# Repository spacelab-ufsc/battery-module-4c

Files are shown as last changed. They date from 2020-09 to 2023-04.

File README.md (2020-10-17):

<h1 align="center">
	BATTERY MODULE 4 CELLS
	<br>
</h1>

<h4 align="center">Electrical power system battery module 4 cells hardware project (sources, outputs, and documentation).</h4>

<p align="center">
    <a href="">
		
	</a>
    <a href="https://github.com/spacelab-ufsc/battery-module-4c/releases">
		
	</a>
	<a href="">
		
	</a>
	<a href="">
		
	</a>
	<a href="https://github.com/spacelab-ufsc/eps2">
		
	</a>
</p>

<p align="center">
  	<a href="#overview">Overview</a> •
  	<a href="#architecture">Architecture</a> •
  	<a href="#interface">Interface</a> •
  	<a href="#version">Version</a> •
  	<a href="#license">License</a> •
  	<a href="#notes">Notes</a>
</p>

<p align="center">
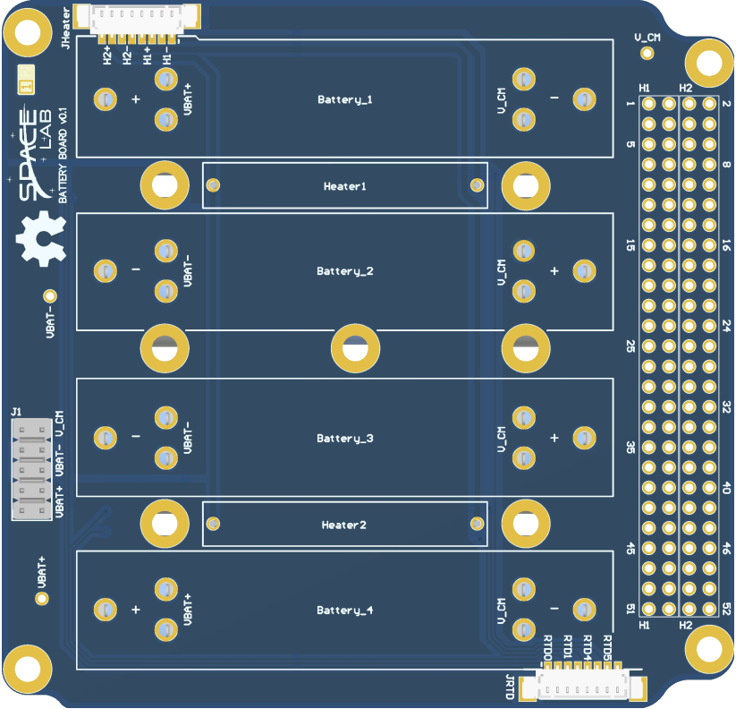
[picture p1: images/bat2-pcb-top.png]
	
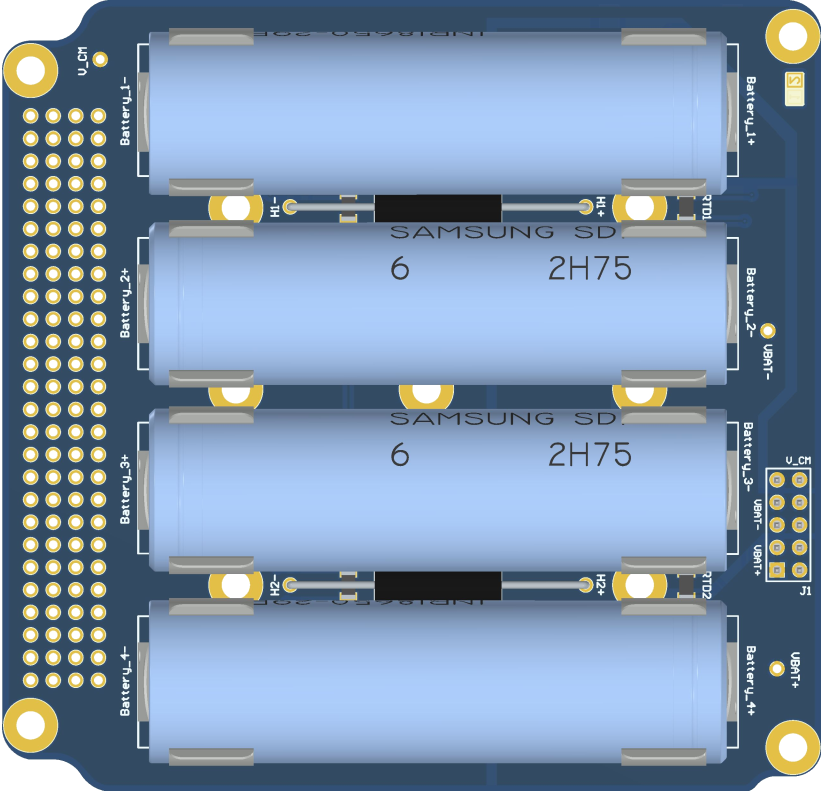
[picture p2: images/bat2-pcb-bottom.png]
	
</p>

## Overview

## Architecture

## Interface

## Version

The current version of the project is v0.1, the status is ```development```.

## License

This project is licensed under CERN Open Hardware License, version 2.

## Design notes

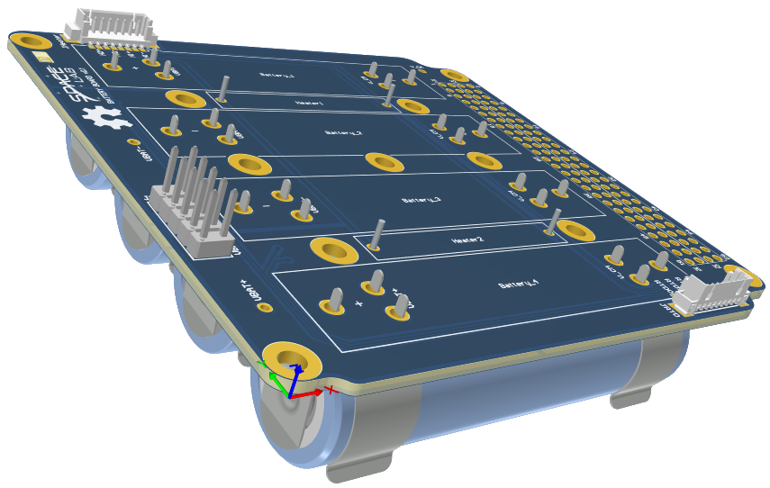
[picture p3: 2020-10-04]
images/bat2-pcb-3d.png

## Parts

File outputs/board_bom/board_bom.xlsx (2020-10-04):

 |  |  | Bill of Materials
 |  |  | Source Data From: | Field=bat2_project
 |  |  | Project: | Field=bat2_project
 |  |  | Variant: | Field=none
 |  |  | Project Code: | Field=BAT2
 |  |  | Report Date: | Field=ReportDate | Field=ReportTime
 |  |  | Print Date: | 2020-10-03 | 20:38:37
# | Column=Designator | Column=Quantity | Column=Manufacturer | Column=Manufacturer Part Number | Column=Partnumber | Column=Description | Column=Package | Column=Footprint | Column=Mount | Column=Fitted
1 | RTD1, RTD2, RTD3, RTD4 | 4 | Heraeus Nexensos |  | 32207595 | Board Mount Temperature Sensors SMD1206(V) Pt 1000 Class B -50 to +130C | 1206 (3216 Metric) | THRMC3216X70N | SMD | Fitted
2 | Battery_1-, Battery_1+, Battery_2-, Battery_2+, Battery_3-, Battery_3+, Battery_4-, Battery_4+ | 8 | Keystone Electronics |  | 54 | Cylindrical Battery Contacts, Clips, Holders & Springs 16-19mm PC BATTERY CLIP | Cylindrical Contact Clip | 54 | Through Hole | Fitted
3 | JHeater, JRTD | 2 | Molex |  | 532610871 | Connector Header Surface Mount, Right Angle 8 position 0.049" (1.25mm) | PicoBlade 53261 | 532610871 | SMD | Fitted
4 | J1 | 1 | SAMTEC |  | 67996-110HLF | Connector | Male Pin Header | HDRV10W64P254_2X5_1270X502X521P | Through Hole | Fitted
5 | PC104A, PC104B | 2 | SAMTEC |  | ESQ-126-39-G-D | PC / 104 Connectors .100" PC/104 Elevated Socket Strip | Forked Elevated Socket | ESQ-126-Y-X-D | Through Hole | Fitted
6 | Heater1, Heater2 | 2 | Vishay |  | RS02B24R00FE12 | Wirewound Resistors - Through Hole 3watts 24ohms 1% | Wirewound Resistors - Through Hole | RESAD3322W86L1422D475 | Through Hole | Fitted

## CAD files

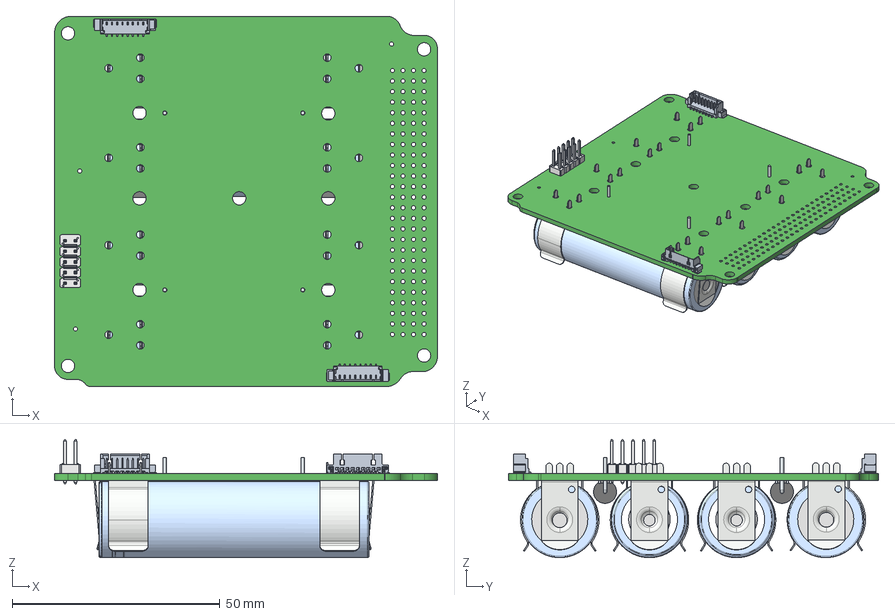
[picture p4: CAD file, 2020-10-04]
outputs/board_3dmodels/step_3dmodel.step
92.1 x 89.1 x 28.5 mm
Boardboard_layout
term1 x 4
term2 x 4
67996-x10_asm_RGB13421772
SimpleBody x 2
Samsung_INR18650-29R x 4
KEYELCO_54 x 8

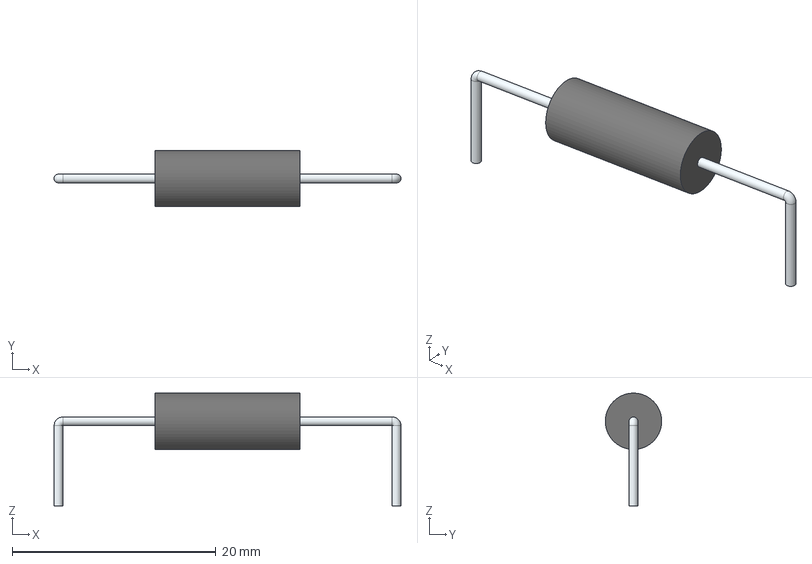
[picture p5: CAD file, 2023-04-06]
sources/ALTIUM_EMBEDDED_MODELS/RS02B24R00FE12.stp
34.1 x 5.53 x 11.1 mm
SimpleBody

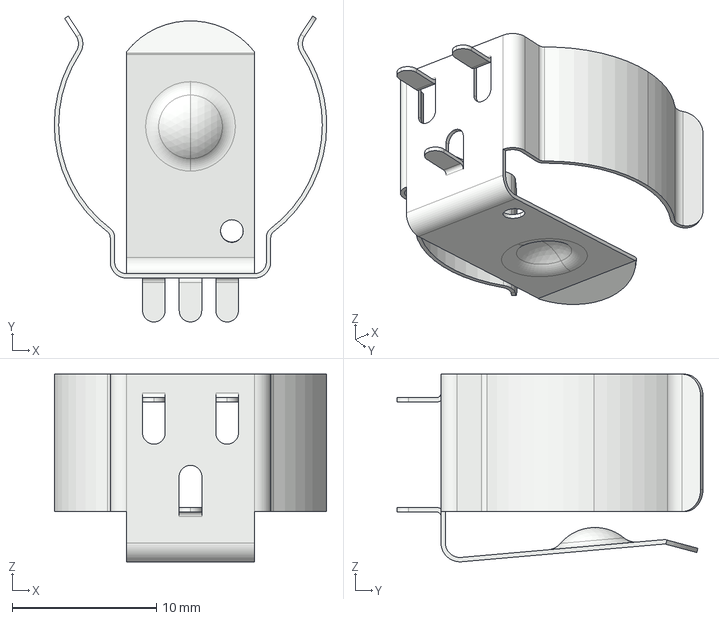
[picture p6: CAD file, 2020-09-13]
sources/ALTIUM_EMBEDDED_MODELS/KEYELCO_54.STEP
18.9 x 21.2 x 13.0 mm

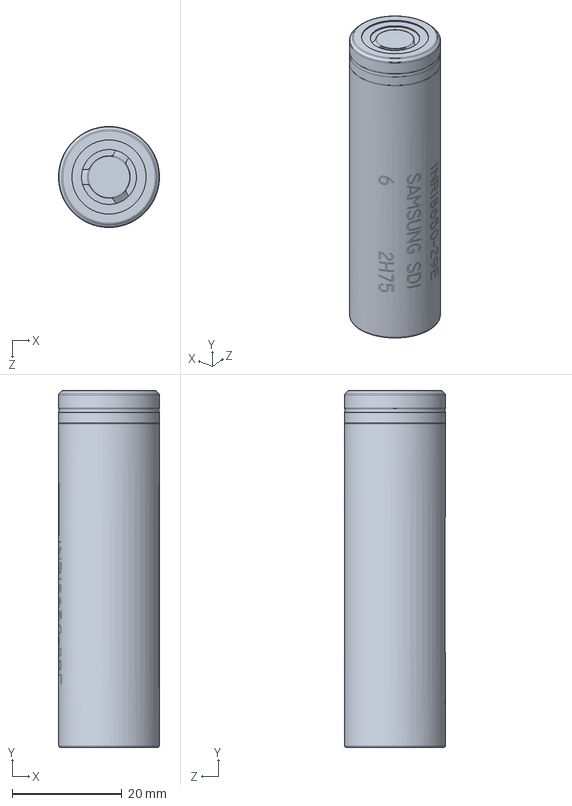
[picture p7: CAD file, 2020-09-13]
sources/ALTIUM_EMBEDDED_MODELS/Samsung INR18650-29R.SLDPRT
18.4 x 64.9 x 18.4 mm

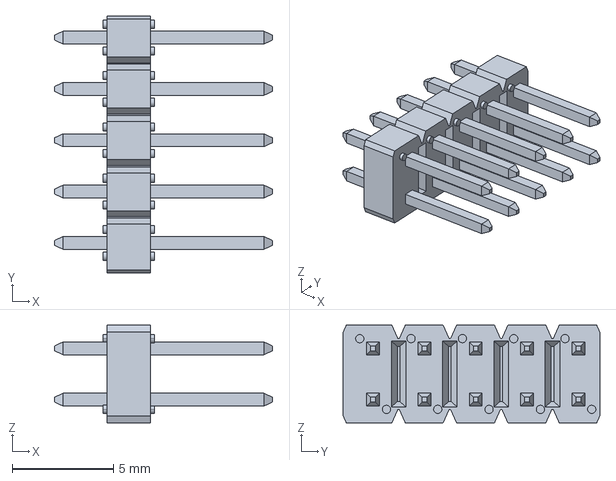
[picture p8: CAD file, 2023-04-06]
sources/ALTIUM_EMBEDDED_MODELS/67996-x10_asm.stp
10.8 x 12.7 x 4.83 mm

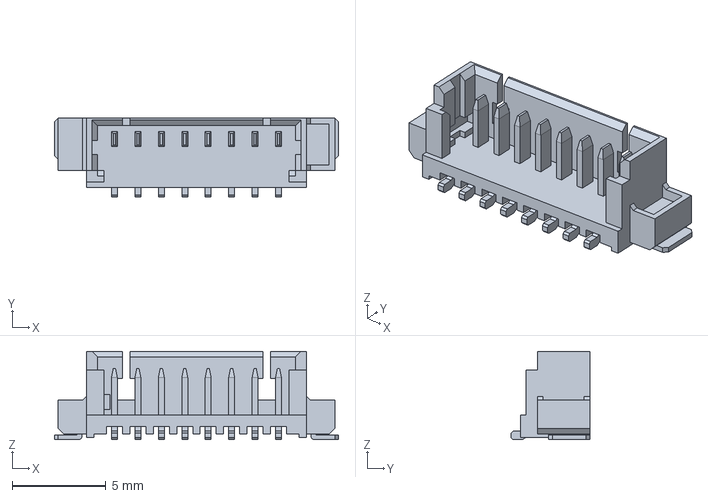
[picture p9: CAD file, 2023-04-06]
sources/ALTIUM_EMBEDDED_MODELS/53398-0871.stp
15.2 x 4.20 x 4.70 mm

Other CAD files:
outputs/board_3dmodels/parasolid_3dmodel.x_t

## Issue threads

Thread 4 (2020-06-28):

Hardware: Review mechanical attachment method

andrempmattos, 2020-06-28:
**Overview:**
It is necessary to review the mechanical attachment for a plastic/polymer cover/wrapper. Since there are 4 batteries and the terminals are closer, shortcuts or detachment could be a problem during the vibration tests patterns. Also, the wrapper presents assembly challenges during the integration, then a simpler method could ease these procedures and improve the overall feasibility.

**Some ideas/recomendations/suggestions to be analysed:**

It could improve the wrapper attachment in the PCB since there are no loose pieces/bolts/washer:
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

Maybe the same method used in other electronic devices with the plastic borders attached even without bolts:

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

YanAzer, 2021-02-10:
Some new images for inspiration:
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
https://www.google.com/imgres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
https://www.google.com/imgres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

YanAzer, 2021-04-28:
@spacelab-ufsc/mechanical some new ideas for the new mechanical case:

1) Add new mouting holes between the batteries, this will require them to be a bit por spaced.

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

2) Add a "tab" on the sides of the pcb to be enable placing the required mouting holes.

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

kiqsmg, 2021-04-28:
Both options can work, but I still prefer the first one because it only requires to create more space between batteries and also helps to have a better fixation points (the closer the fixations are, the less vibration problems and bending possibility).

Closed 2021-06-15.

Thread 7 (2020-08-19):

Hardware: Change PC104 conector partnumber

andrempmattos, 2020-08-19:
Change the PC104 partnumber to **SSW-126-01-G-D**.

andrempmattos, 2020-09-29:
The PC104 should not be soldered in this board. Then, the partnumber is not important anymore.

Closed 2020-09-29.

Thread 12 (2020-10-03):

Change the 8 pin PicoBlade vertical connector to the right angle version

YanAzer, 2020-10-03:
Current one is [0533980871](https://www.digikey.com/en/products/detail/molex/0533980871/699072), for better compatibility this component should be changed to the right angle version [0532610871](https://www.digikey.com/en/products/detail/molex/0532610871/699100).

andrempmattos, 2020-10-04:
The current version uses a 0532610871 (the right one) in the BOM file, but the 0533980871 in the board footprint/3D render. Then, it is important to update the footprint/3D render as suggested.

YanAzer, 2021-01-22:
@andrempmattos fixed solved issue via commits 626e60e940f685972dce35918c38ef1ae062296c and e58543fbc46f1a04be224ae19969c023d9c77b60, new outputs were generated via 2595ccffb678d09d9985b111dd0b83d6000be54a.

Closed 2021-01-22.

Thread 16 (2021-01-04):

Evaluate the battery choosed

andrempmattos, 2021-01-04:
https://ieeexplore.ieee.org/document/8281113

andrempmattos, 2021-01-04:
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

YanAzer, 2021-07-03:
I think we can close this issue, what you do you think @andrempmattos @mgm8?

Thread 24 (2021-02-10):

See a battery supplier alternative

YanAzer, 2021-02-10:
It would be better to choose another battery from the issue https://github.com/spacelab-ufsc/battery-module-4c/issues/16 and its provider.

YanAzer, 2021-05-27:
This issue is already covered in another repository.

Closed 2021-05-27.

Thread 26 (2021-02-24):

Hardware: Make the "bms" schematic sheet

YanAzer, 2021-02-24:
This schematic will have the battery controller IC https://github.com/spacelab-ufsc/battery-module-4c/issues/17 and auxiliary circuitry.

YanAzer, 2021-04-04:
@zdaniz22 next time remember to add the commits with its hashtag of its respective issue if you can, if not you can manually add the commit in the comments, just like what i am doing now 16429ef43a68dd4f7830682af033f33ba348b9a7

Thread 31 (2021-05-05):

Hardware: Evaluate 0 ohm jumper to isolate energized battery pack during integration

YanAzer, 2021-05-05:
For the next version of the BAT4C the batteries will be directly soldered to the PCB, it might be a good option to have a zero ohm jumper easily acessed on the side of the PCB to be soldered after the integration is done.

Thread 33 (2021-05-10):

Move the battery cells to the top side of the board

mgm8, 2021-05-10:

YanAzer, 2021-06-11:
@mgm8 it was discussed that the mounting holes previously on v0.1 for the mechanical batteries case would not be very pratical and might cause structure integrity problems because of the width of the material been drilled. #34

Closed 2021-06-11.

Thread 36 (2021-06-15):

Hardware: Evaluate the 3 wire configuration for RTDs

YanAzer, 2021-06-15:
Current design makes the 2 wire RTDs connections very inaccurate. Instead of 4 it can be used 2 RTDs with more precision in this 3 wire configuration directly below the heaters.
Reference: https://www.ti.com/lit/an/sbaa275/sbaa275.pdf?ts=1623687678741&ref_url=https%253A%252F%252Fwww.google.com%252F

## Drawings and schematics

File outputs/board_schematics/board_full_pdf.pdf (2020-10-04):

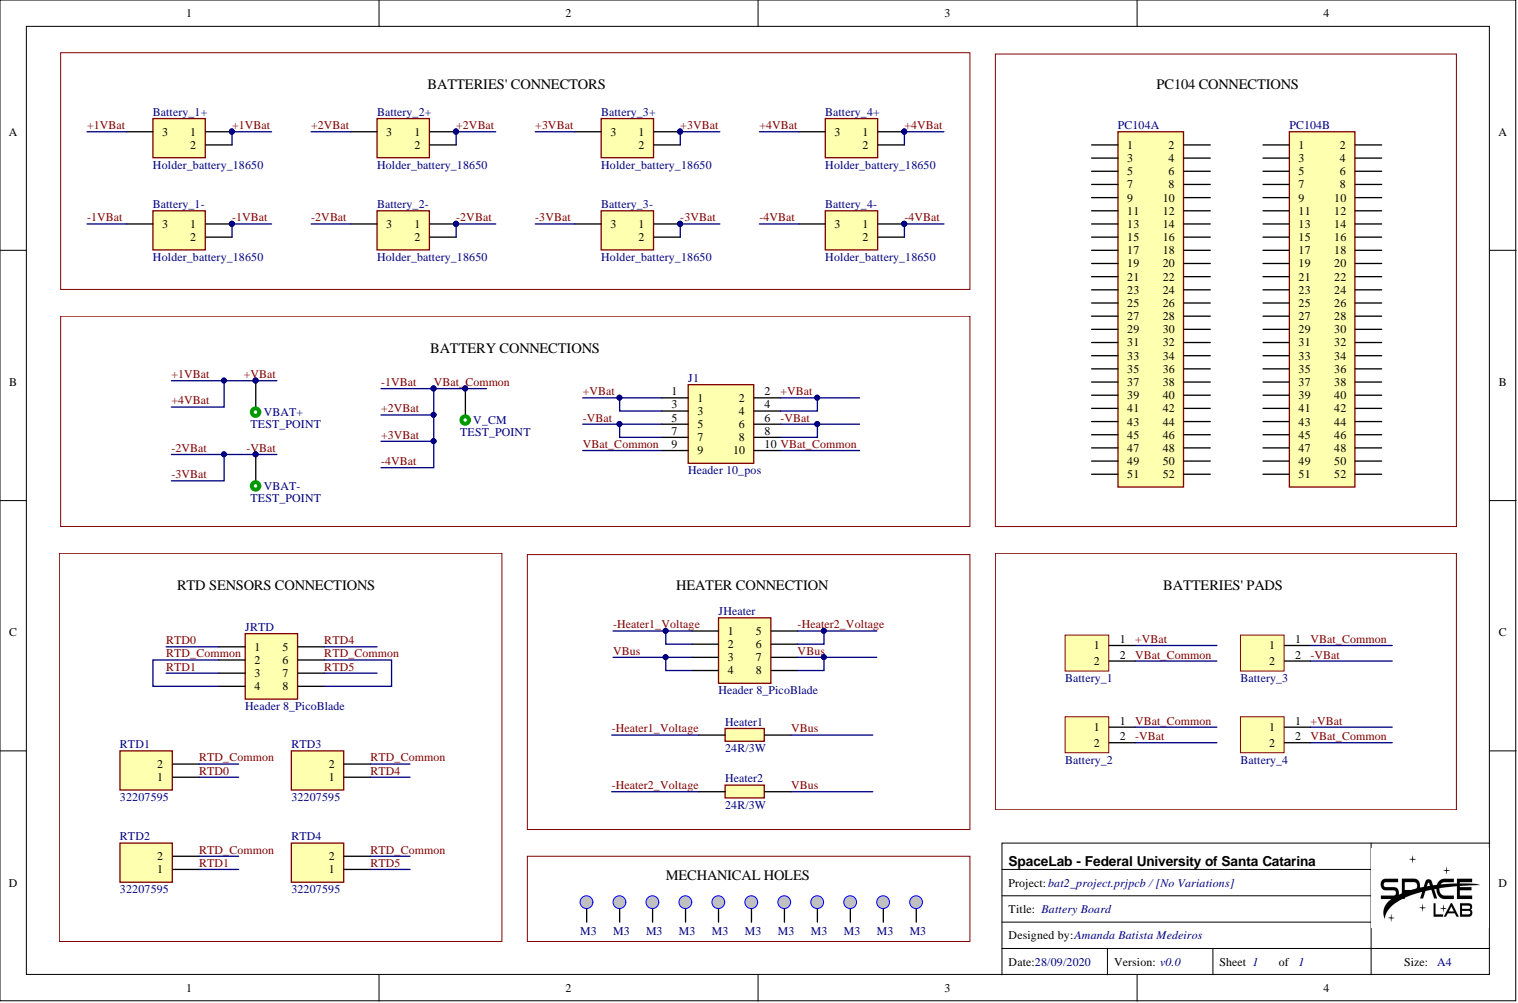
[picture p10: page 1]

SpaceLab - Federal University of Santa Catarina

Designed by:Amanda Batista Medeiros

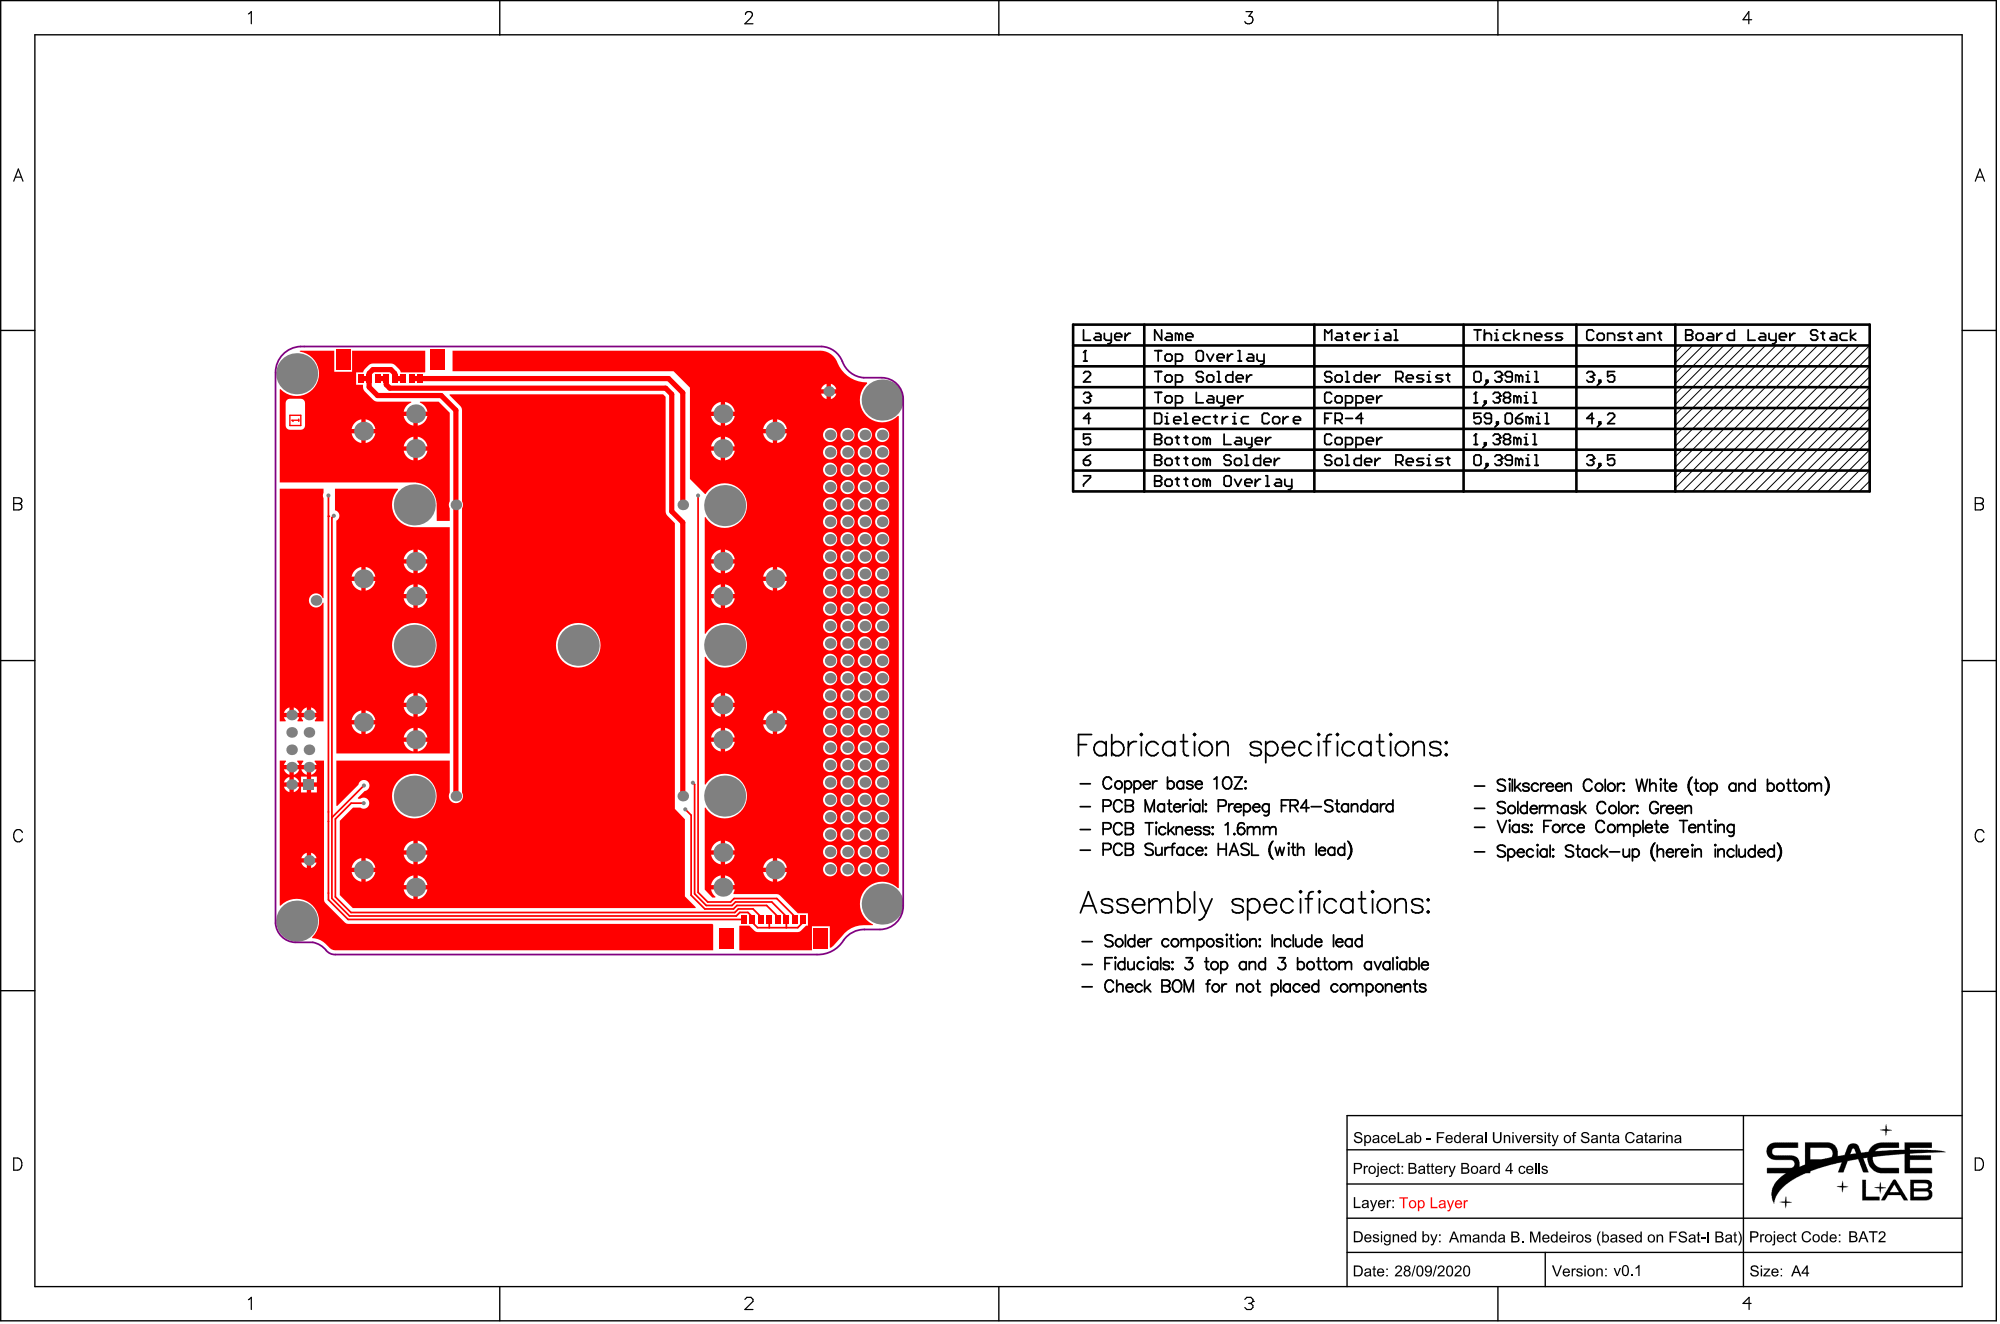
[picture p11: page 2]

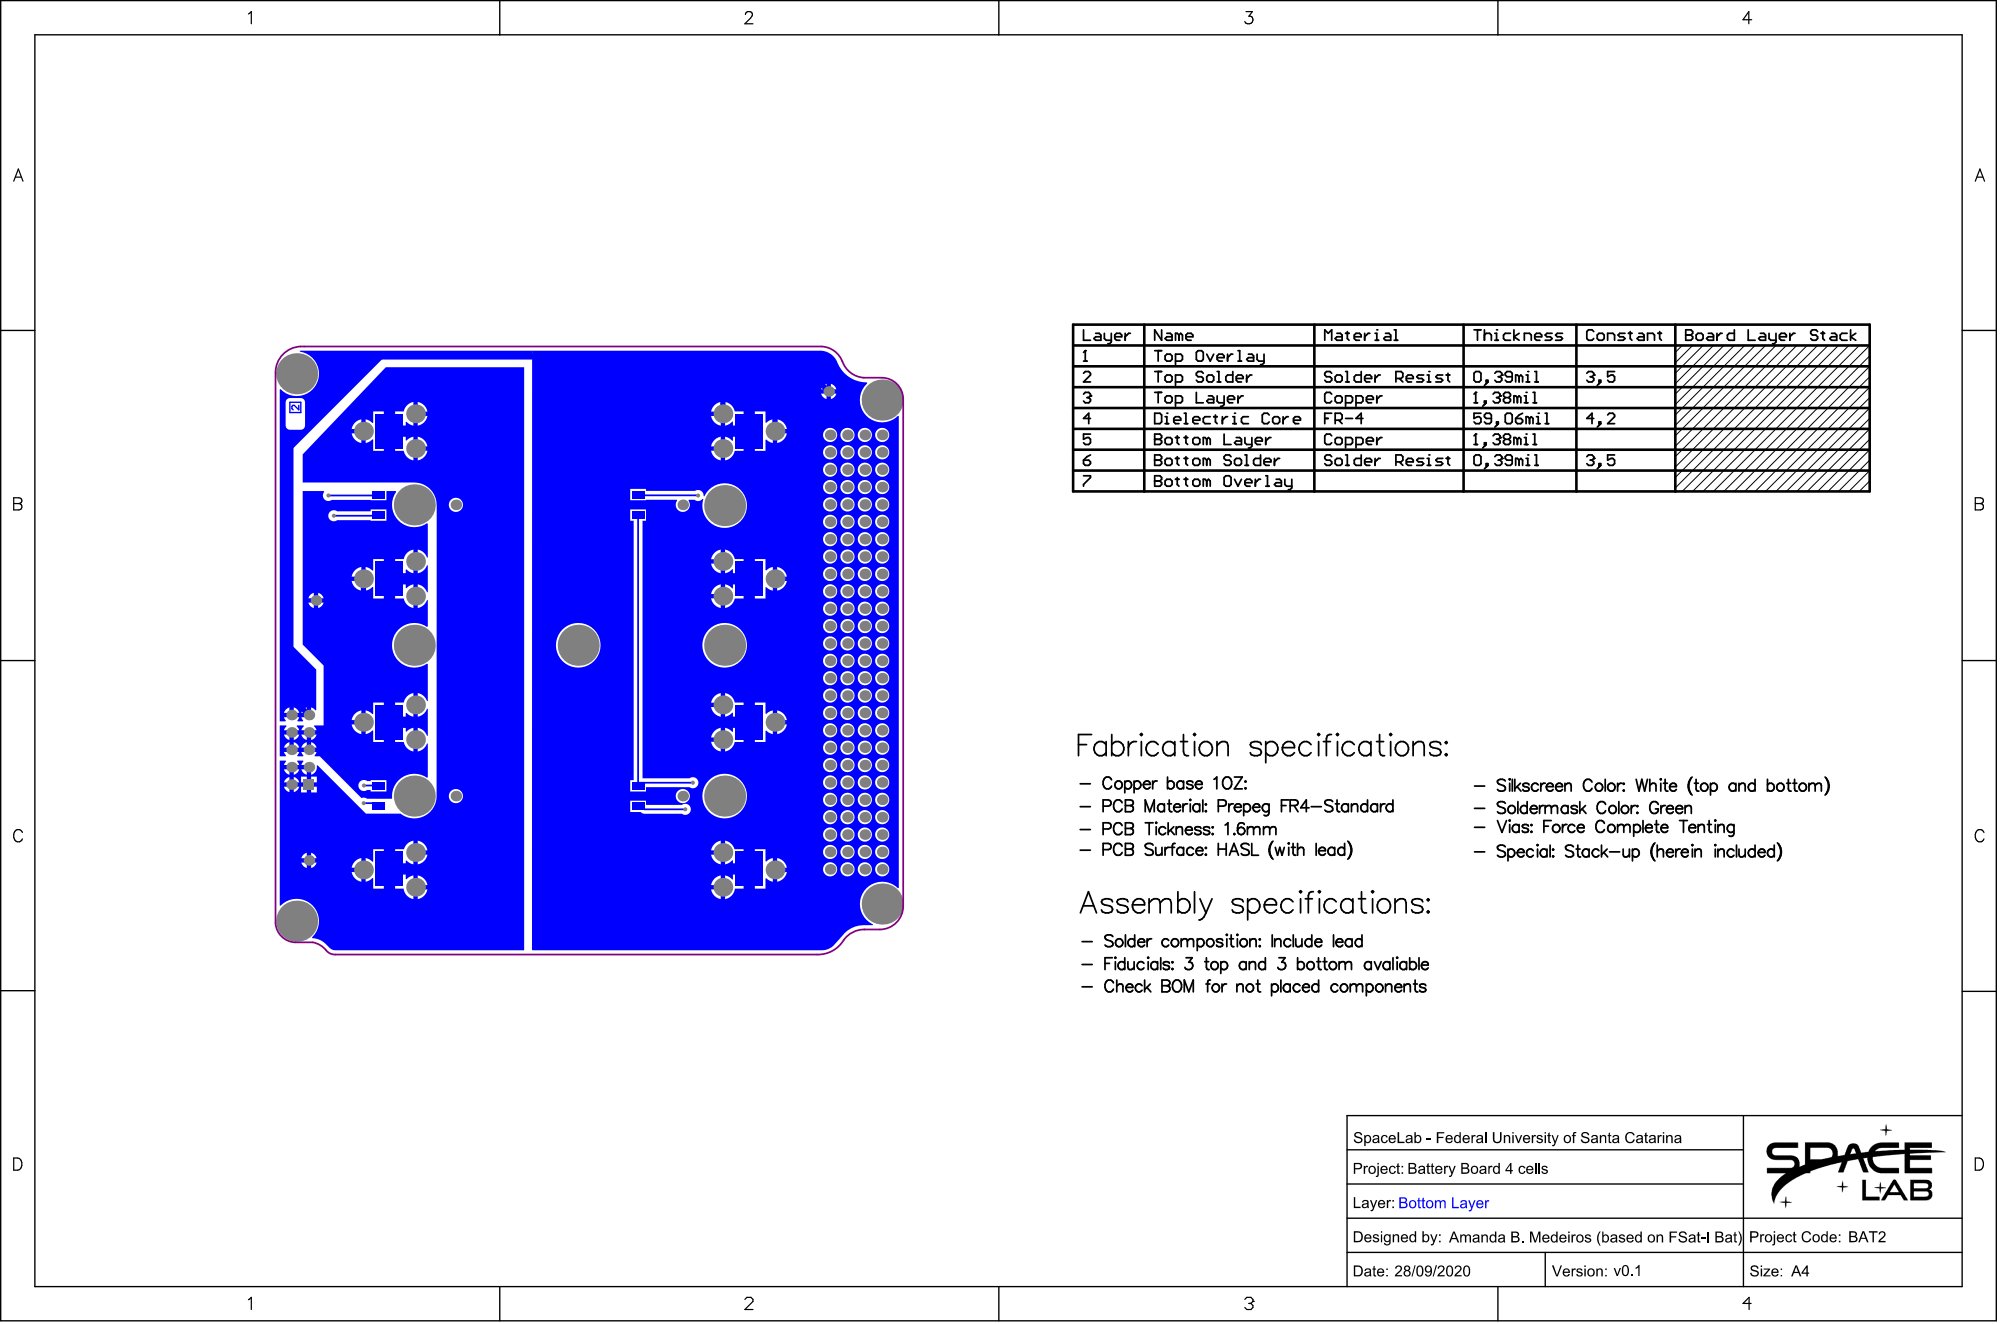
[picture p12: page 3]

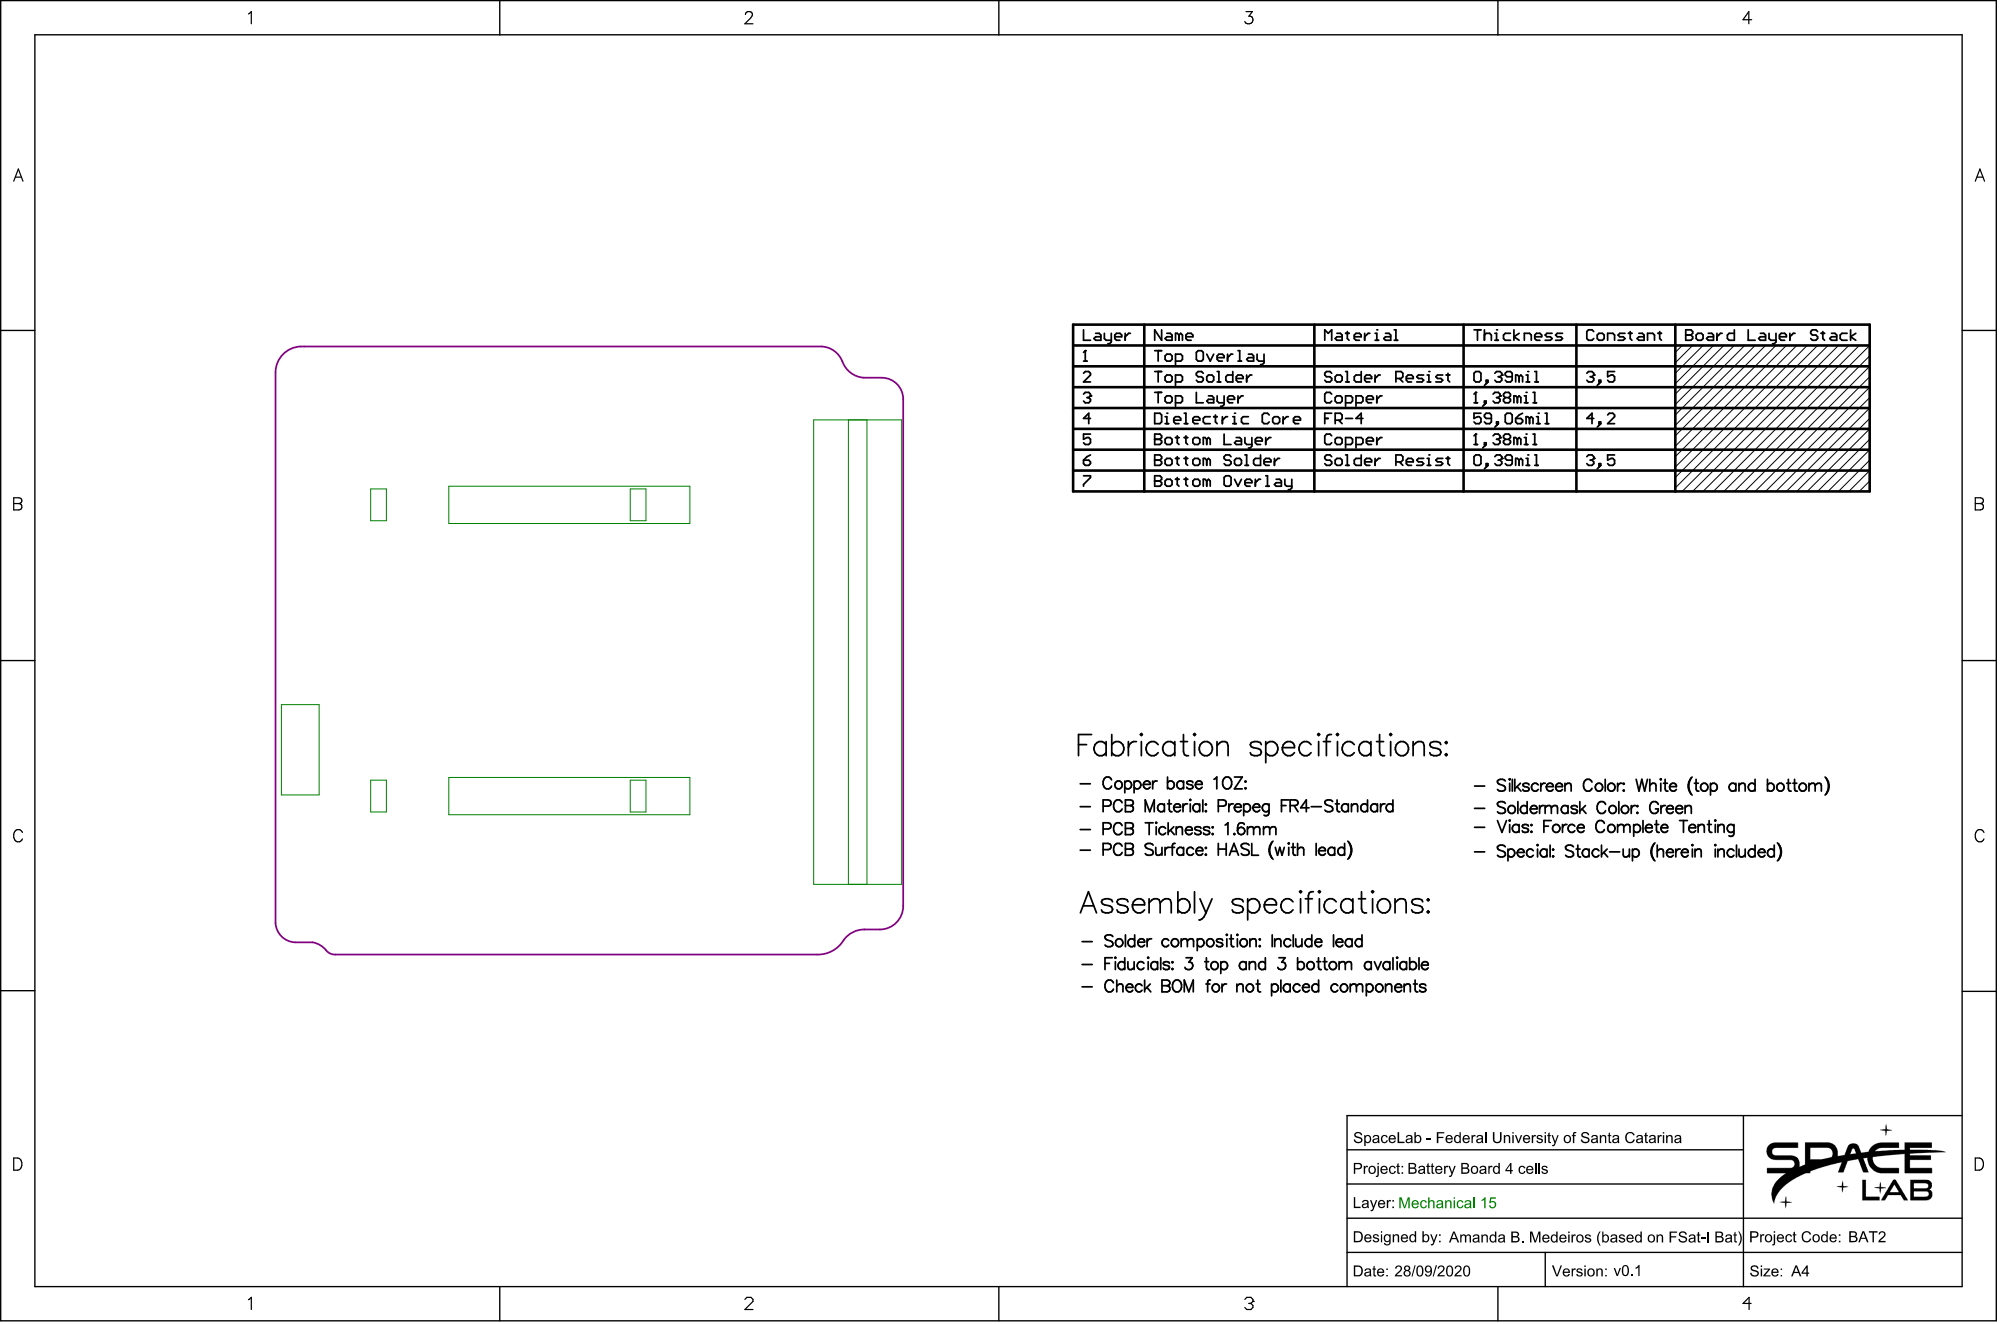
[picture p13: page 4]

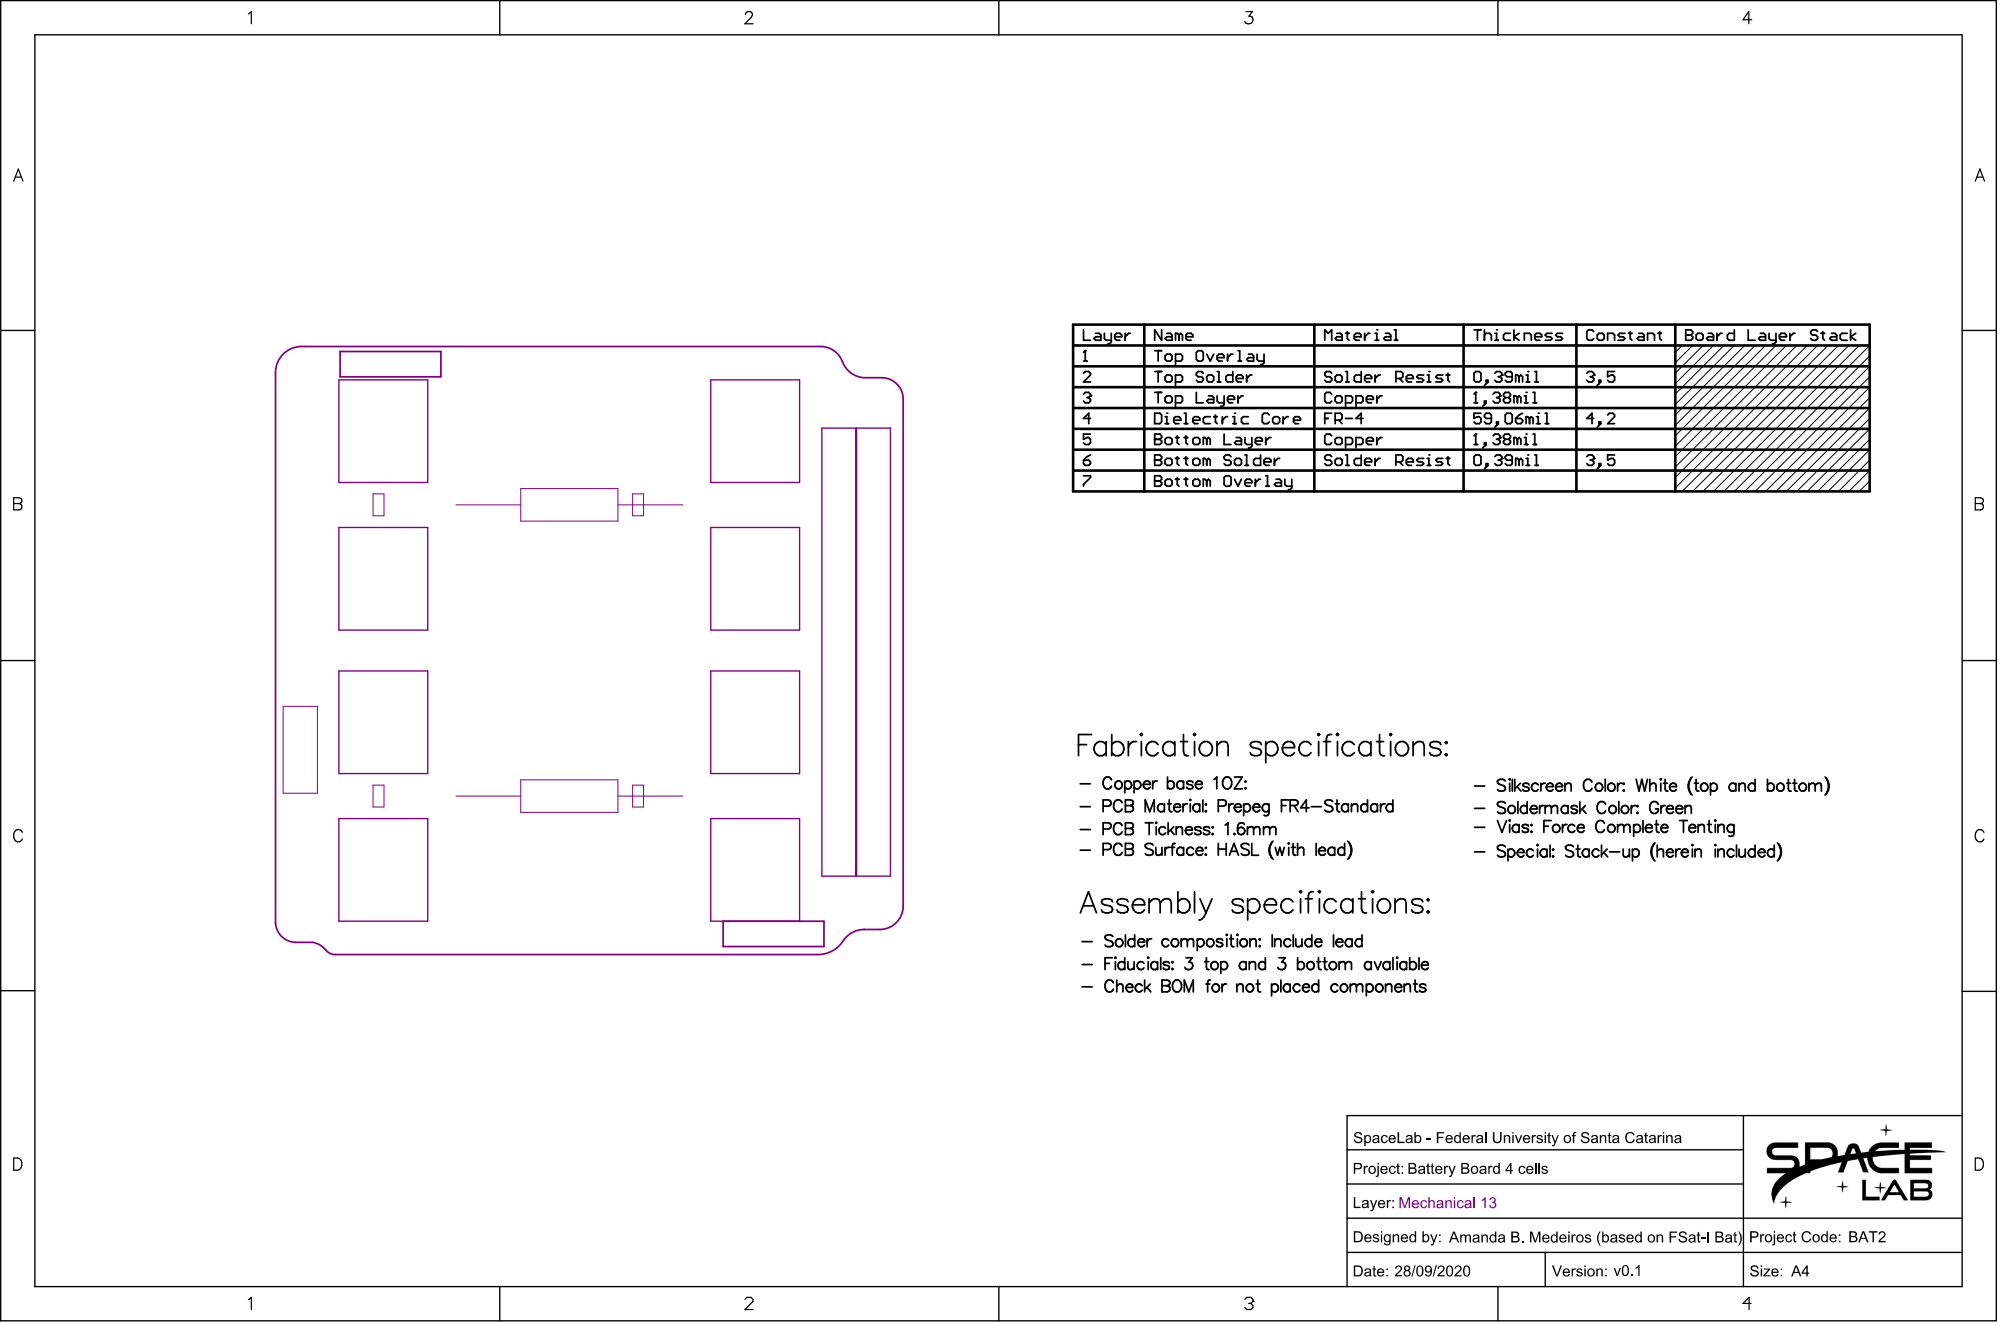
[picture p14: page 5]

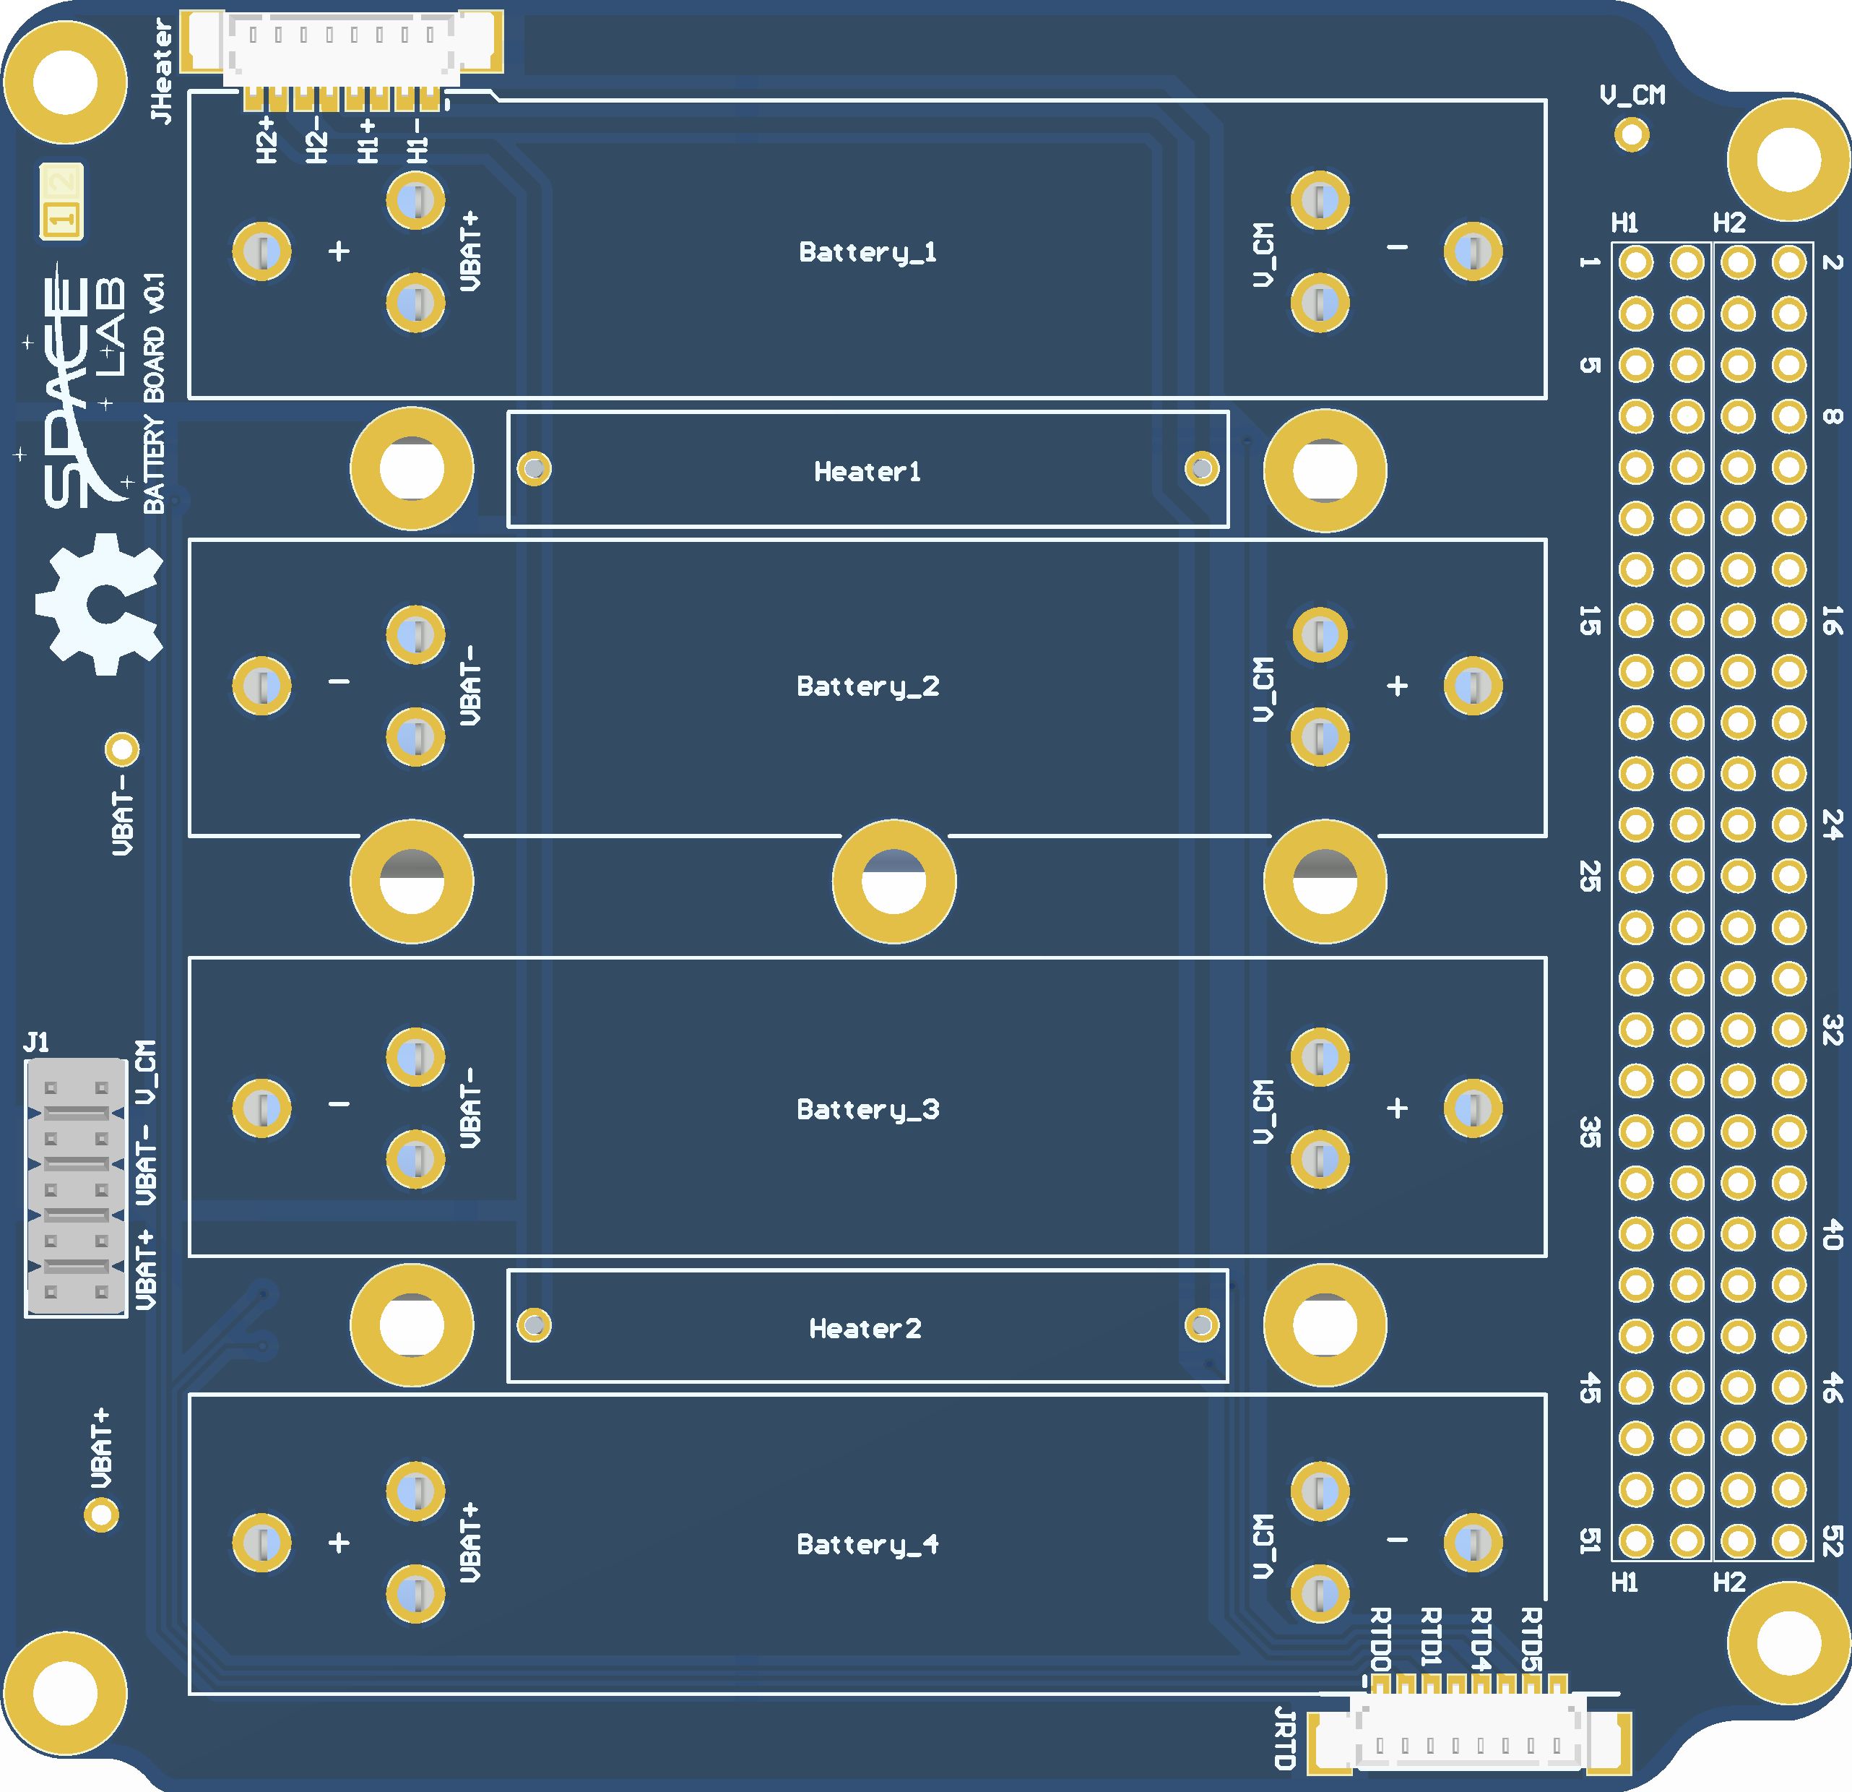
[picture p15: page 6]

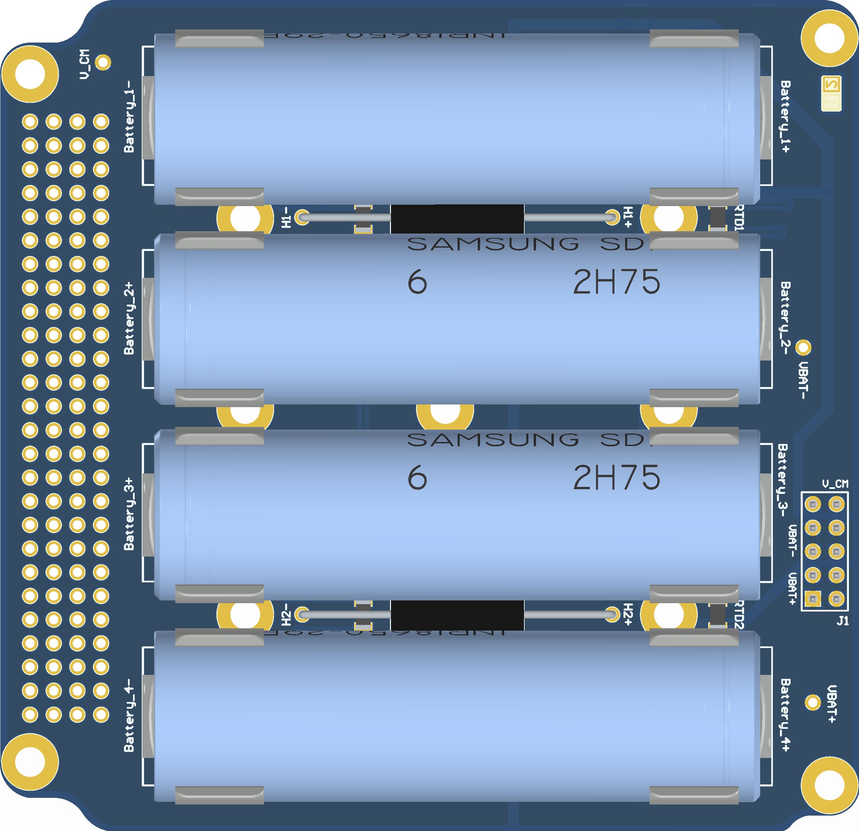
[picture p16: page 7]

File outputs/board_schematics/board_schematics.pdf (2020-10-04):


SpaceLab - Federal University of Santa Catarina

Designed by:Amanda Batista Medeiros

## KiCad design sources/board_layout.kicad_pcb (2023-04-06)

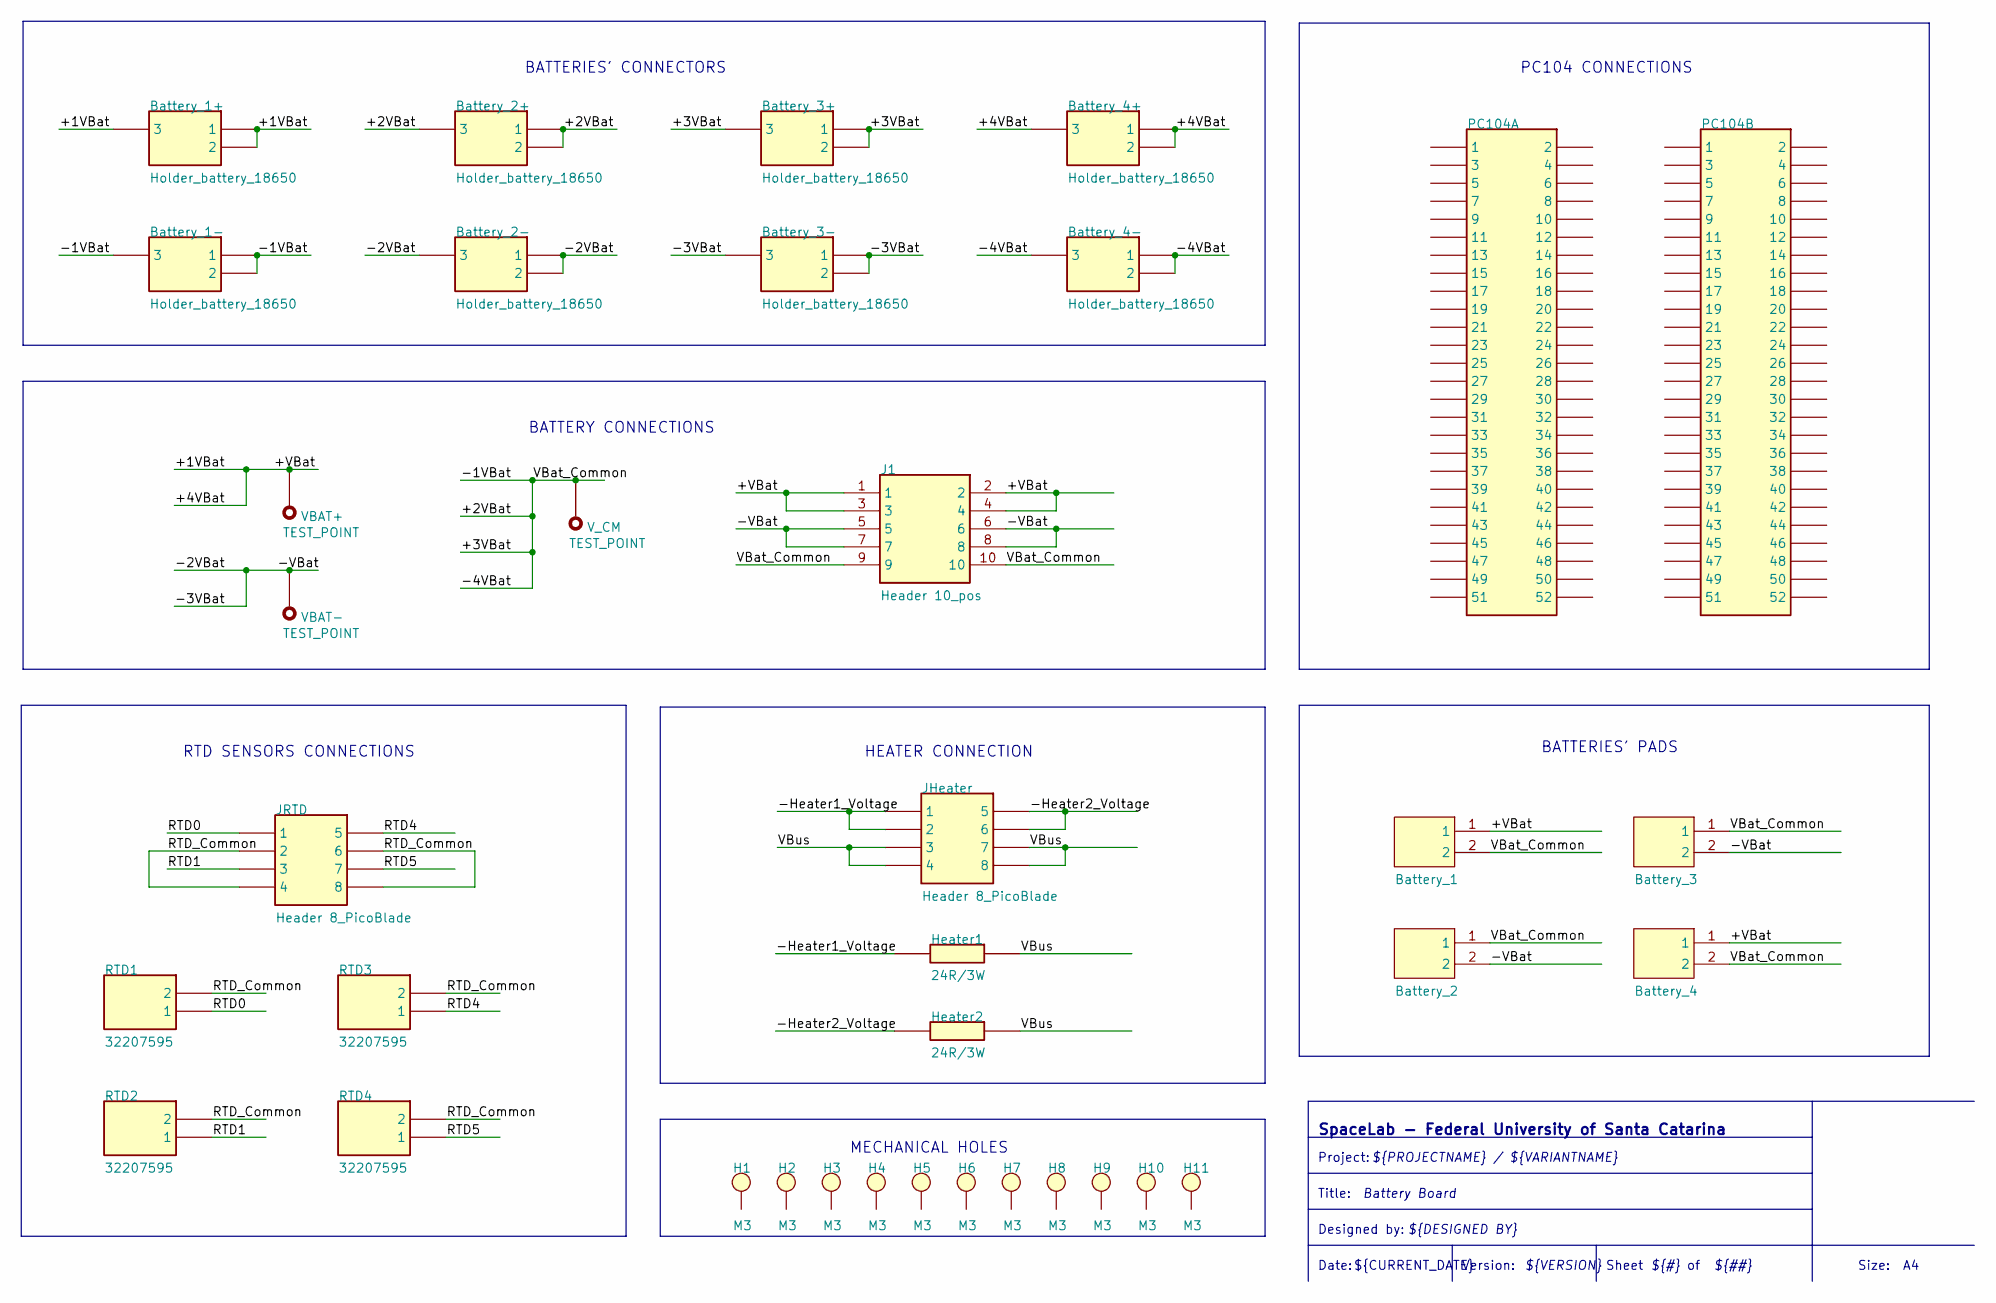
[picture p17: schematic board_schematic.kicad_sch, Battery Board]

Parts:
Battery_1, Battery_2, Battery_3, Battery_4: BATTERY
Battery_1+, Battery_1-, Battery_2+, Battery_2-, Battery_3+, Battery_3-, Battery_4+, Battery_4-: Holder_battery_18650; 54; MANUFACTURER_PART_NUMBER 54; MOUSER PART NUMBER 534-54
H1, H2, H3, H4, H5, H6, H7, H8, H9, H10, H11: M3; M3 hole
Heater1, Heater2: 24R/3W; RESAD3322W86L1422D475; MANUFACTURER_PART_NUMBER RS02B24R00FE12
J1: Header 10_pos; _Users_User_Desktop_Backup F__2020_Personal GitKraken_batte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; MANUFACTURER_PART_NUMBER 67996-110HLF; MOUSER PART NUMBER 649-67996-110HLF
JHeater: Header 8_PicoBlade; 53398-0871; MOUSER2 PART NUMBER 538-53398-0871
JRTD: Header 8_PicoBlade; 53398-0871; MOUSER2 PART NUMBER 538-53398-0871
PC104A, PC104B: ESQ-126-39-G-D; ESQ-126-Y-X-D; MANUFACTURER_PART_NUMBER ESQ-126-39-G-D; MOUSER PART NUMBER 200-ESQ12639GD
RTD1, RTD2, RTD3, RTD4: 32207595; THRMC3216X70N; MANUFACTURER_PART_NUMBER 32207595
VBAT+: TEST_POINT; Test_Point
VBAT-: TEST_POINT; Test_Point
V_CM: TEST_POINT; Test_Point

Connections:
+1VBat: Battery_1.1, Battery_1+.1, Battery_1+.2, Battery_1+.3, Battery_4.1, Battery_4+.1, Battery_4+.2, Battery_4+.3, J1.1, J1.2, J1.3, J1.4, VBAT+.1
+2VBat: Battery_1.2, Battery_1-.1, Battery_1-.2, Battery_1-.3, Battery_2.1, Battery_2+.1, Battery_2+.2, Battery_2+.3, Battery_3.1, Battery_3+.1, Battery_3+.2, Battery_3+.3, Battery_4.2, Battery_4-.1, Battery_4-.2, Battery_4-.3, J1.9, J1.10, V_CM.1
-2VBat: Battery_2.2, Battery_2-.1, Battery_2-.2, Battery_2-.3, Battery_3.2, Battery_3-.1, Battery_3-.2, Battery_3-.3, J1.5, J1.6, J1.7, J1.8, VBAT-.1
-Heater1_Voltage: Heater1.1, JHeater.1, JHeater.2
-Heater2_Voltage: Heater2.1, JHeater.5, JHeater.6
RTD0: JRTD.1, RTD1.1
RTD1: JRTD.3, RTD2.1
RTD4: JRTD.5, RTD3.1
RTD5: JRTD.7, RTD4.1
RTD_Common: JRTD.2, JRTD.4, JRTD.6, JRTD.8, RTD1.2, RTD2.2, RTD3.2, RTD4.2
VBus: Heater1.2, Heater2.2, JHeater.3, JHeater.4, JHeater.7, JHeater.8

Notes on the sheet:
SpaceLab - Federal University of Santa Catarina
BATTERIES' PADS
Size:
${CURRENT_DATE}
${##}
${DESIGNED BY}
${TITLE}
RTD SENSORS CONNECTIONS
BATTERIES' CONNECTORS
${PROJECTNAME} / ${VARIANTNAME}
BATTERY CONNECTIONS
Designed by:
Title:
PC104 CONNECTIONS
Version:
HEATER CONNECTION
${VERSION}
MECHANICAL HOLES
Date:
Project:
Sheet
${#}

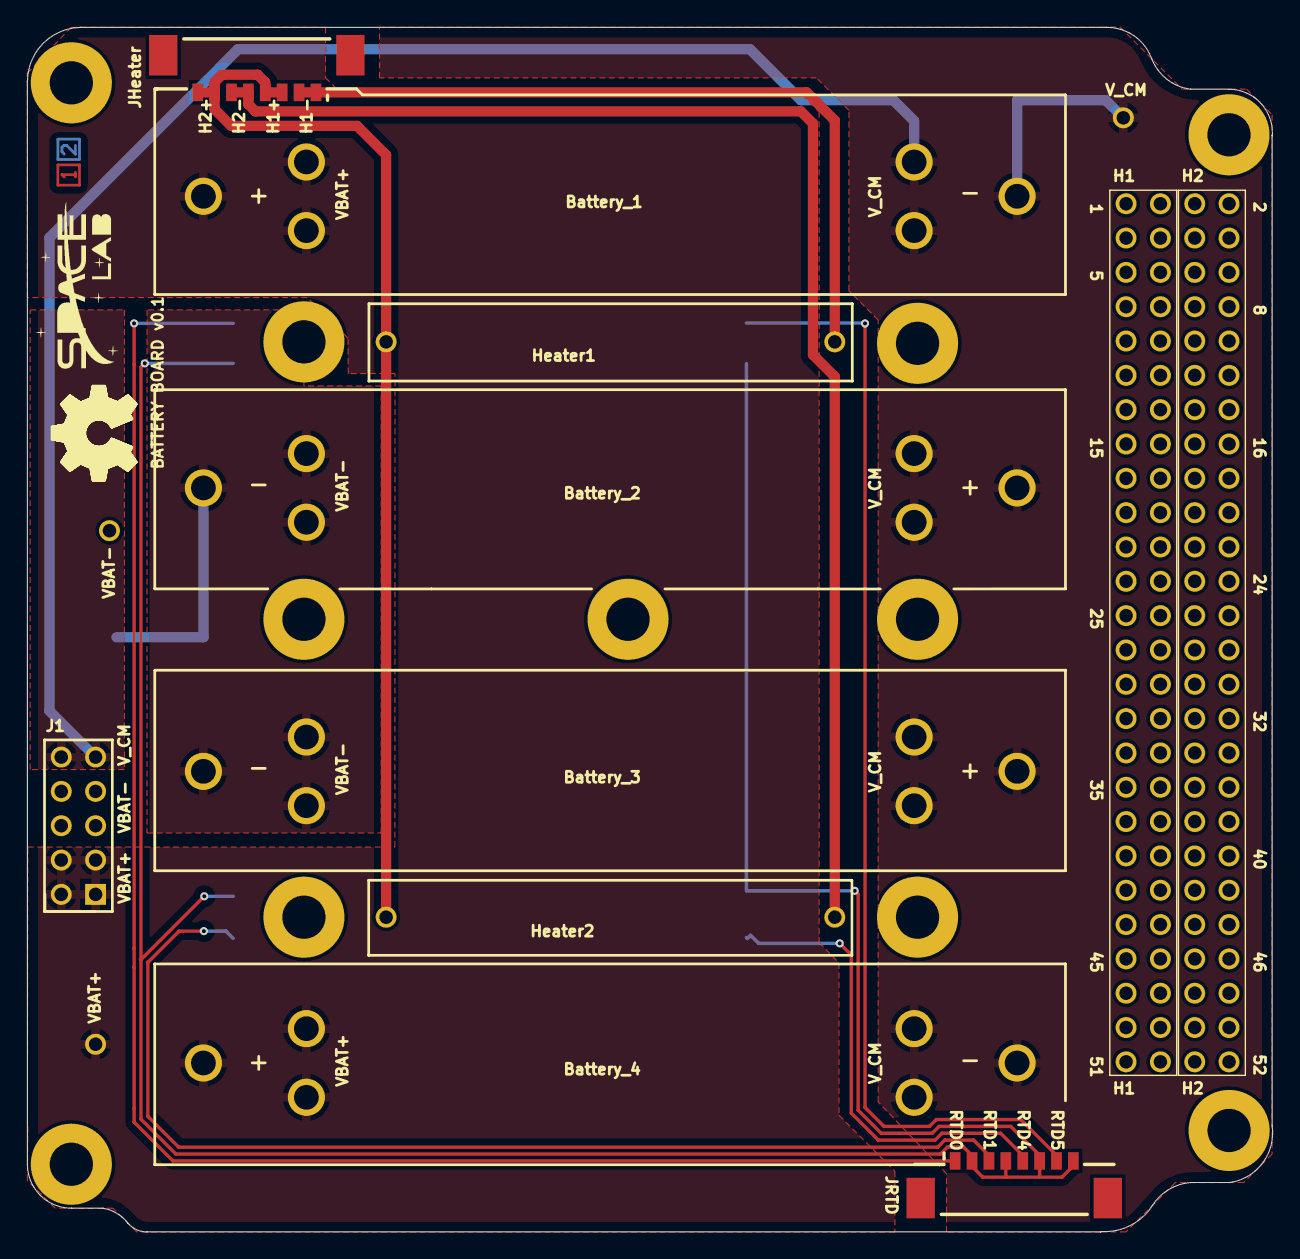
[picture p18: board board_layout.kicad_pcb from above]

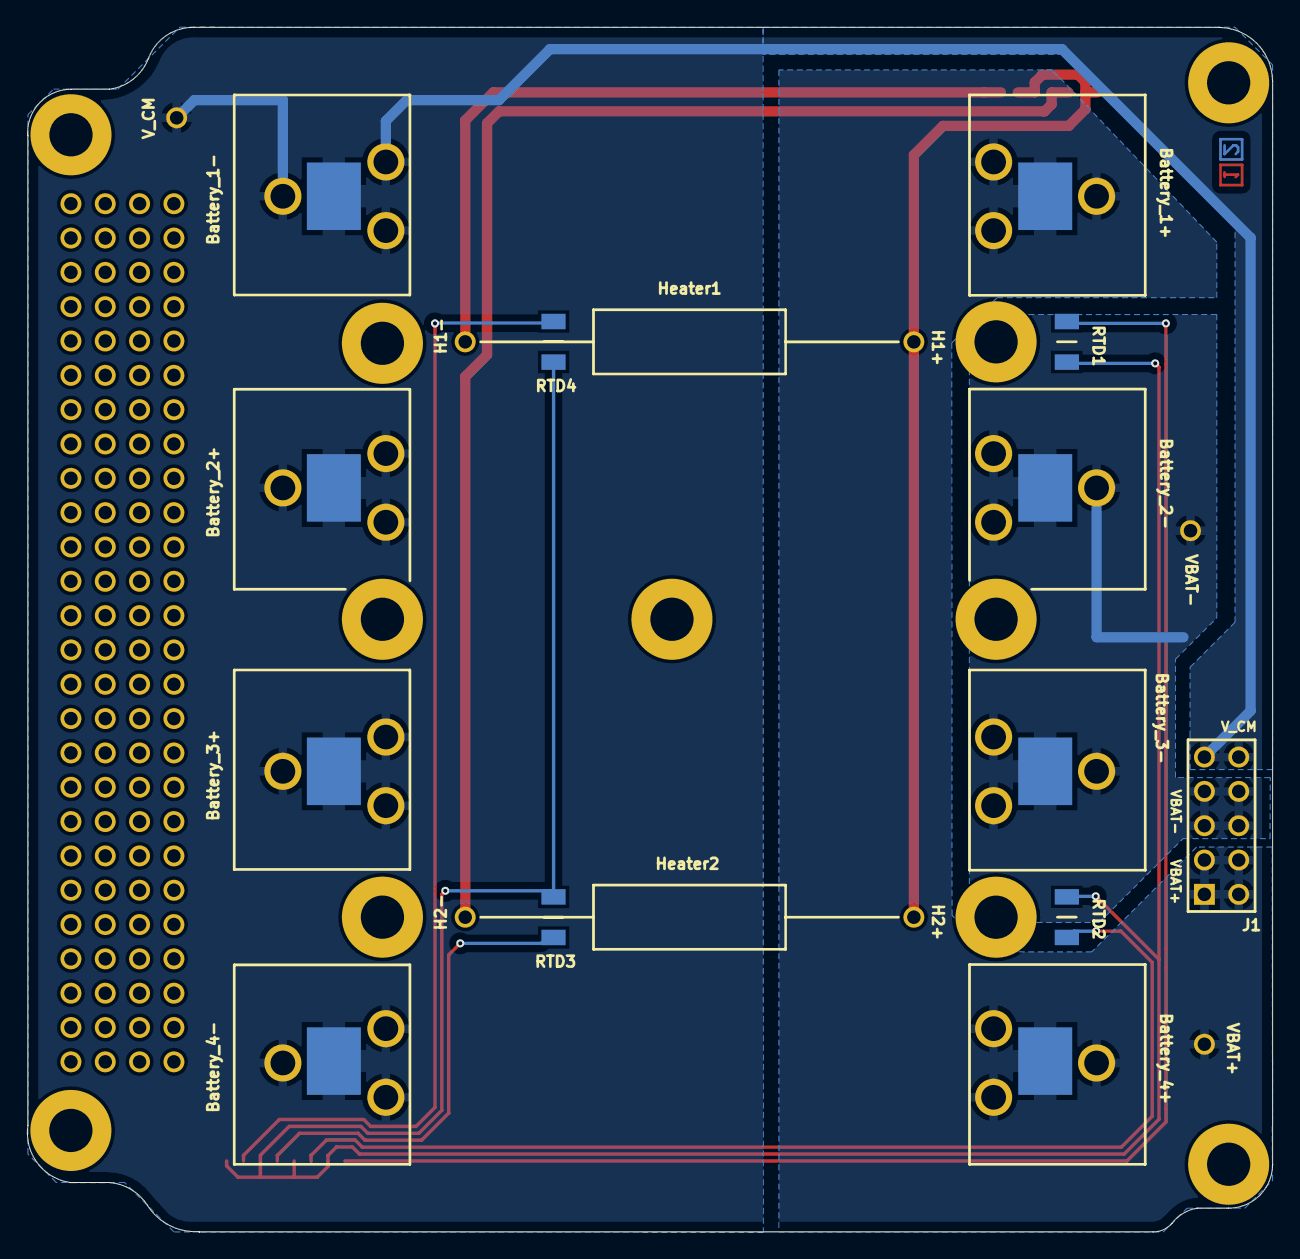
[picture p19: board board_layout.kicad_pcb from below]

Board: 2 copper layers, 92.1 x 89.1 mm, 37 parts (18 on the bottom side), 11 nets.

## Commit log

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2020-05-07 hardware: adding preliminary board shape and holes #2
    [PCB_Project_Batteries_V2.PcbDoc, PCB_Project_Batteries_V2.PrjPCB, Sheet_Project_Batteries_V2.SchDoc]
2020-05-18 hardware: deleting resistors, adding step files, placing components #3
    Deleting resistors for replacement; additional step files of batteries, battery clips, preliminary resistors, PC104 connectors; placing first positioning of batteries, clips, sensors and resistors.
    [PCB_Project_Batteries_V2.PcbDoc, Sheet_Project_Batteries_V2.SchDoc]
2020-05-27 hardware: replacing connectors and components, organizing files #4
    changing placement layers of picoblades, sensors, heaters and battery connectors; changing project files because of an minor error
    [PCB_Project_Batteries_V2.PcbDoc, Sheet_Project_Batteries_V2.SchDoc]
2020-05-27 hardware: adding preliminary battery nets #5
    adding battery connectors polygon nets for posterior connection
    [PCB_Project_Batteries_V2.PcbDoc]
2020-05-27 hardware: re-ranging heater's picoblade connections #6
    re-ranging net names for the heater's picoblade for compatibility with EPS board
    [PCB_Project_Batteries_V2.PcbDoc, Sheet_Project_Batteries_V2.SchDoc]
2020-05-27 hardware: changing RTD's pins, removing pin numbers #7
    - rearranging RTD's picoblade pins for interface with EPS;
    - removing unnecessary information in the schematics.
    [Sheet_Project_Batteries_V2.SchDoc]
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2020-05-27 hardware: editing battery nets, changing sensors positions #9
    - connecting the battery clips nets to the J1 connector (EPS power connector);
    - removing sensors positions for future decision of them;
    [PCB_Project_Batteries_V2.PcbDoc]
2020-05-27 hardware: arranging sensors positions, adding battery pads reference #10
    - placing new positions for the sensors, which was only possible by changing some of the battery nets;
    - adding a reference for future battery pads if the connectors aren't needed
    [PCB_Project_Batteries_V2.PcbDoc]
2020-05-28 hardware: changing RTD's positions, connecting nets #11
    - changing RTD 2 and 4 position for better placement of the nets;
    - connecting the nets onto the RTD's picoblade.
    [PCB_Project_Batteries_V2.PcbDoc]
2020-06-02 hardware: editing and replacing nets and vias #12
    - changes in heater's nets width and placement
    - changes in the rtd's nets and vias width
    - replacing rtd's nets for better positioning
    [PCB_Project_Batteries_V2.PcbDoc]
2020-06-21 hardware: adding libraries and creating testpoint #13
    - creating a schematic and a PCB library
    - creating a testpoint symbol for the schematic
    - adding the testpoint footprint
    [PCB_Project_Batteries_V2.PrjPCB]
2020-06-21 hardware: changing connections in the sheet #14
    - changing connectors' wires for better visualization
    [Sheet_Project_Batteries_V2.SchDoc]
2020-06-21 hardware: adding testpoints to the sheet #15
    - placing the testpoints in the power connections
    [Sheet_Project_Batteries_V2.SchDoc]
2020-06-21 hardware: adding and placing testpoints in the PCB #16
    - updating sheet connections to the PCB
    - placing testpoints far from battery clips, but near original nets
    [PCB_Project_Batteries_V2.PcbDoc]
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2020-06-24 hardware: adding the new battery symbols to the schematic #20
    [Sheet_Project_Batteries_V2.SchDoc]
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2020-06-25 hardware: updating battery symbols to the schematic #22
    [Sheet_Project_Batteries_V2.SchDoc]
2020-06-25 hardware: placing battery pads into the PCB #23
    [PCB_Project_Batteries_V2.PcbDoc]
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2020-06-28 hardware: adding logo and board's name #28
    - minor labeling changes
    - adding FloripaSat's logo and board's name to the PCB project
    - final version of V2.0
    [PCB_Project_Batteries_V2.PcbDoc]
2020-07-02 hardware: updating schematics #30
    - deleting different common paths and combining them to a single one
    [Sheet_Project_Batteries_V2.SchDoc]
2020-07-02 hardware: updating PCB after schematic changes #31
    - connecting all commons and deleting extra testpoint
    - aligning drill holes
    [PCB_Project_Batteries_V2.PcbDoc]
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2020-08-17 hardware: minor changes in the silkscreen, adding GOLDS patch #32
    Also minor changes in the schematic template.
    [PCB_Project_Batteries_V2.PrjPCB, Sheet_Project_Batteries_V2.SchDoc]
2020-08-18 documentation: updating schematics' pdf and adding project's BOM #6
    - rewriting component descriptions and names
    - adding an excel file with list of components
    - adding a pdf file of the same list
    [BOM_PCB_Project_Batteries_V2.xlsx]
2020-08-18 hardware: updating project, adding used 3D step files #34
    - minor changes such as linking the footprints to the libraries
    - adding battery, battery clips and PC104 step files
    [PCB_Project_Batteries_V2.PrjPCB, Sheet_Project_Batteries_V2.SchDoc]
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2020-09-28 hardware: schematics: Updating sheet template and adding mechanical holes
    [Sheet_Project_Batteries_V2.SchDoc]
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2020-09-29 hardware: layout: Updating logos, render color and board name
    [PCB_Project_Batteries_V2.PcbDoc]
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2020-09-29 hardware: layout: Fixing DRC non-critical errors
    [PCB_Project_Batteries_V2.PcbDoc]
2020-09-29 hardware: layout: Adding sheet template, layer names, dimensions and fabrication info
    [PCB_Project_Batteries_V2.PcbDoc]
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2020-09-29 hardware: Updating folders structure and refactoring nomenclature. close #8
    [PCB_Project_Batteries_V2.PcbDoc, PCB_Project_Batteries_V2.PrjPCB, Sheet_Project_Batteries_V2.SchDoc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]
2020-09-29 hardware: outputs: Adding all fabrication, output and documentation files
    [bat2_project.prjpcb, board_bom.xls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]
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2020-10-03 hardware: outputs: board_bom: Swaping manually the picoblade vertical component to the right angle version #5
    [board_bom.xlsx]
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

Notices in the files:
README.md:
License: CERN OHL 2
